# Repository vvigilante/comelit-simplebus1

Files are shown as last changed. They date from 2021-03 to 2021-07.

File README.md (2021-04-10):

# Comelit Simplebus 1 compatible smart audio intercom
If you live in an older building with an audio-only door phone based on the SimpleBus version 1, you may have no choice for upgrading to a smart alternative. This project aims to build an open implementation of a smart doorphone compatible with the comelit simplebus 1 audio protocol, to replace ordinary units such as 2408w/a, 2708W and 2xx8W in general.

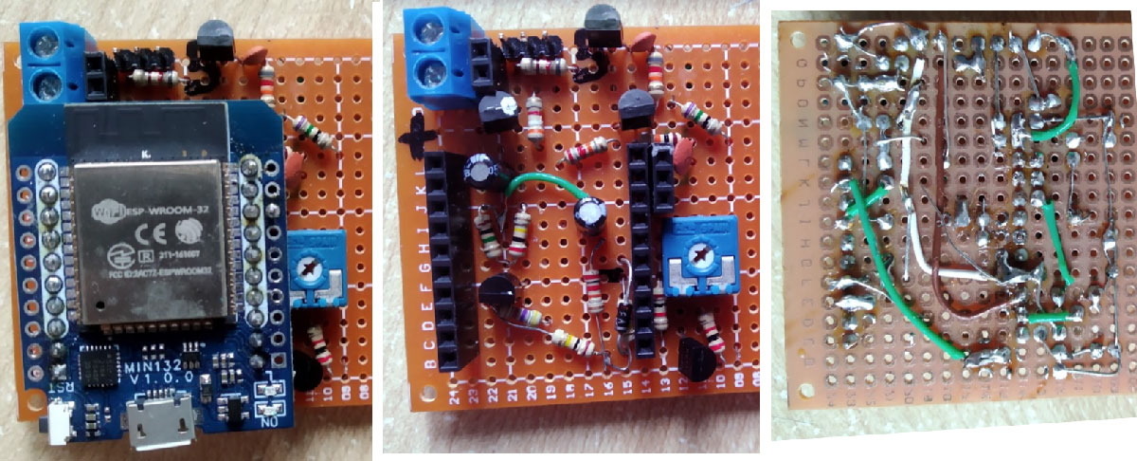
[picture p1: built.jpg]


## Content of the repository
| Dir | Content 
------- | --- 
| libsimplebus | Arduino library that allows to interface with the digital bus 
| web_intercom | Arduino sketch that implements a complete intercom operated by a web interface. 
| sketch_webmonitor | **(temporarily broken)** Arduino sketch that implements a websocket based https interface that logs the messages on the bus, allows to listen to the audio signal and to transmit audio signals from the computer mic. It also allows to initiate calls on the bus, useful for testing. 

## Wiring

Wire according to the wiring diagram; **mind the polarity of the bus!**

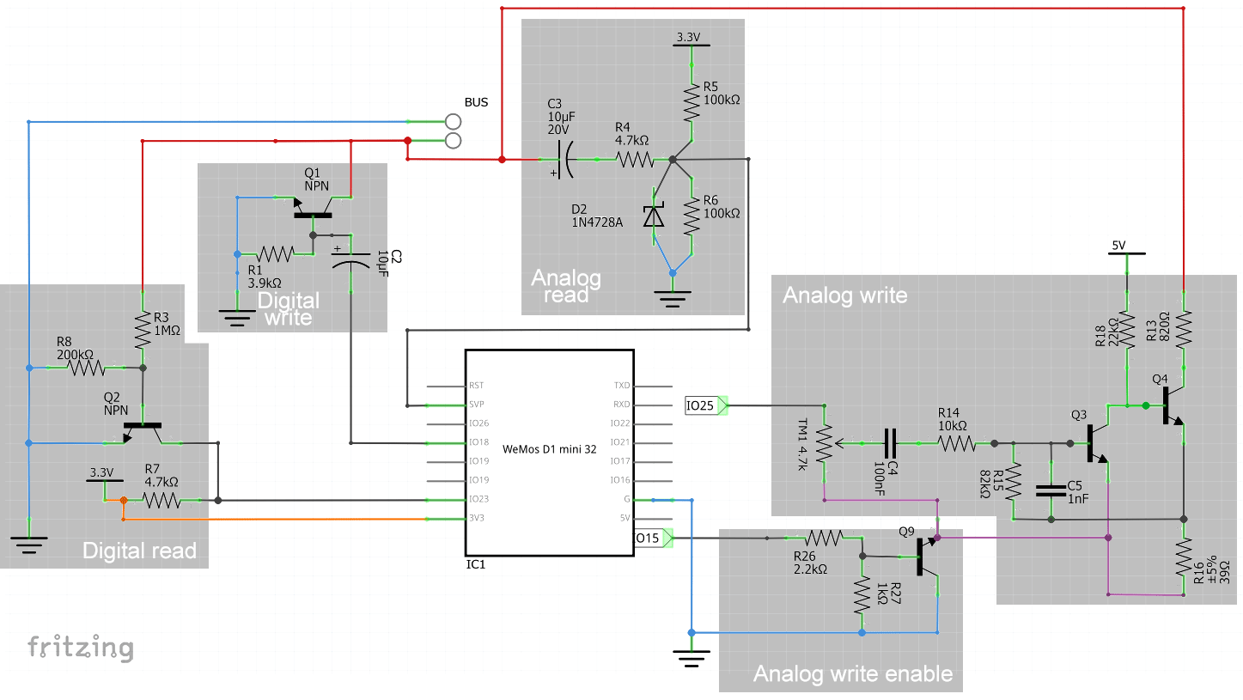
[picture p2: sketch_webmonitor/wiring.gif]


Tested on Wemos D1 mini32 (esp32 arduino core 1.0.5).

### Known issues
* Feedback from the PC speaker back into the mic.

## Protocol

The protocol features a ~24V bus. The units communicate through a digital protocol, by shorting the bus to produce short and long pulses.

Digital messages are composed of a 6 bit command, 8 bit "internal unit id" and 4 bit checksum. The start of a message is signaled by a longer pulse.
The recipient acknowledges every message by sending a sequence of three short pulses.

The audio is sent back and forth as an analog signal in base band on the bus itself once the communication has been established. Its peak-to-peak amplitude is about 2.5 volts.

Example of a communication
```
time: [41.404s] message: [000011 10110000 1010 - CALL 13 chkOK]
time: [41.457s] ack
time: [47.914s] message: [100010 10110000 1010 - PUP1 13 chkOK]
time: [47.961s] ack
time: [48.128s] message: [100011 10110000 0110 - PUP2 13 chkOK]
time: [48.172s] ack
time: [49.524s] message: [000010 10110000 0010 - OPEN 13 chkOK]
time: [49.571s] ack
time: [51.316s] message: [000010 10110000 0010 - OPEN 13 chkOK]
time: [51.362s] ack
time: [53.545s] message: [000010 10110000 0010 - OPEN 13 chkOK]
time: [53.592s] ack
time: [58.221s] message: [010010 10110000 1010 - HUP 13 chkOK]
time: [58.256s] ack
time: [68.616s] message: [111111 11111111 0111 - CLEAR 255 chkOK]
time: [68.952s] message: [111111 11111111 0111 - CLEAR 255 chkOK]
time: [69.289s] message: [111111 11111111 0111 - CLEAR 255 chkOK]
time: [69.626s] message: [111111 11111111 0111 - CLEAR 255 chkOK]
time: [69.963s] message: [111111 11111111 0111 - CLEAR 255 chkOK]
```

## Acknowledgements
Thank you to Antonio Avallone for his help with the electronics of this project

## Previous work
* http://stdio.be/blog/2014-08-17-Fixing-the-intercom-with-logic-analyzer/1
* https://hackaday.com/2019/10/27/reverse-engineering-a-two-wire-intercom/

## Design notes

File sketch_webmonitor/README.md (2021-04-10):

A web interface that:
- shows the bus status (clear / busy in a call, etc)
- logs the messages received on the bus
- allows to start a call to an internal unit
- shows the waveform read from the bus through ADC+DMA
- plays the waveform in real time through the browser

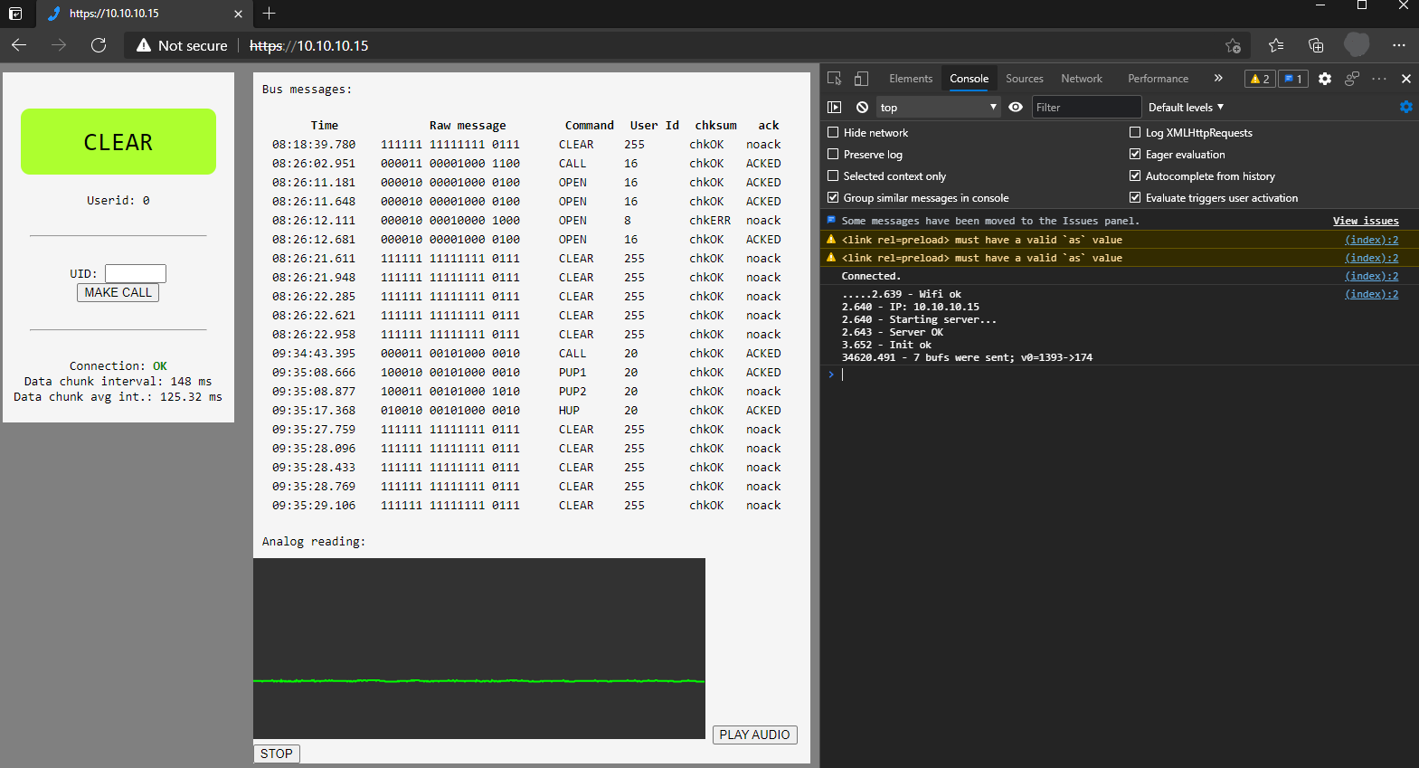
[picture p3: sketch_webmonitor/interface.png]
Interface


## Wiring

Wiring diagram

For reading the bus we use a voltage divider (R2,R3) connected to Q2; Q2 will open during the pulses on the bus, bringing the signal high on IO23 through the R7 pull-up resistor; IO23 is configured to handle rising-edge interrupts.

For writing to the bus we short the two ends of the bus through Q1, which is controlled by the pin IO18 through a capacitor.

For reading the analog voltages through the ADC (on pin GPIO35, SVP) we use the C3 capacitor to remove the 24V direct component, we then bias the signal again using the voltage divider (R5,R6).
The clipper circuit (D2, R4) is meant to limit the voltage spikes caused by the digital communication on the bus. The audio signal has an amplitude of 2.5 v peak to peak.

For writing analog voltages on the bus we use the two stage amplifier made of Q3 and Q4. The signal is generated by the DAC on GPIO25 and fed through a potentiometer and an high-pass filter to the amplifier.
The amplifier is connected to ground through Q9, that can be used to turn the amplifier on and off through a GPIO pin (e.g. 16 in the figure, 15 in the sketch)

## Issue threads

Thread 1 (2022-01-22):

[Dumq Question] Wich power is use external or bus

cynnfx, 2022-01-22:
Hello,

First thank for this work.

I asking myself if this project use bus power or extrnal one.

And if it's use extrenal power if we can use the bus one, like real intercom device (and [this project](https://github.com/plusvic/simplebus2-intercom)

Thanks,

vvigilante, 2022-01-22:
This project uses external power.
It cannot be otherwise because there is not enough power on the bus to power a wifi enabled chip continuously.

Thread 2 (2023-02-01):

Dogital Write

Gurkenflieger, 2023-02-01:
Hello, why are you connecting the digital write output transistor Q1 over a capacitor C2 and resistor R1 , minimizing fluctuations? Why not connecting it directly with a resistor to the IO18.

vvigilante, 2023-02-01:
Let me open by saying that I don't know exactly what's going on.

I think the capacitor there will prevent the micro from holding the gate down for a long time (e.g. in case of software issues and such). You only need to send pulses on the bus, and my understanding is that the capacitor allows you to do that.

Correct me if all this doesn't make sense to you

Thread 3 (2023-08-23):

Identify transistors

vinicentus, 2023-08-23:
Hello!

Would it be possible to document the model numbers of the transistors used in the different parts of the cricuit? As of now they are missing.

I'm trying to build something similar but it's hard to figure out what the different transistors are used for and what specs they need to have.

Br.
Vincent

vvigilante, 2023-08-23:
I used bc327/8 all over.

vinicentus, 2023-08-23:
Thank you! That helps a lot!

vinicentus, 2023-08-23:
Do you want this issue closed or should I leave it open? Btw, [this](https://github.com/vvigilante/comelit-simplebus1/blob/main/sketch_webmonitor/README.md) was very helpful as well for understanding the circuit.

vinicentus, 2023-08-23:
May I still ask what current gain was used? Here are a couple of different versions of the BC327 (more info [here](https://www.el-component.com/bipolar-transistors/bc327) under the Hfe seciton)

vvigilante, 2023-08-23:
BC337-25 maybe? Found that in my purchase history.
I don't have the exact data handy unfortunately. I just grabbed whatever transistors I had laying around at the time. I'm not an EE, but I think it's not going to matter a whole lot. There was not though put into the choice of transistor, basically.

vinicentus, 2023-08-23:
Okay.
Thank you for the answer!
I'll try to build this unit and see how it goes.

vinicentus, 2023-08-26:
Did you by any chance mean BC337? Because they are NPN transistors, as in the schematic. BC327 are PNP transistors, which aren't used at all (it seems).

vvigilante, 2023-08-26:
Yes BC337-25

vinicentus, 2023-08-26:
Yeah, okay, thanks :D

Closed 2023-08-23.

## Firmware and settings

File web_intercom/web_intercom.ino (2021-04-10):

#include "SimplebusIntercom.h"
#include "Logger.h"
#include "WebsocketLogger.h"
#include "audio.hpp"
#include "server.hpp"
#include "SerialLogger.h"
#include <ArduinoOTA.h>

#define RING_INTERVAL_MS 1000

// CONFIGURATION
#define BUS_ID 27
#define BUS_RECEIVE_PIN      GPIO_NUM_5
#define BUS_TRANSMIT_PIN     GPIO_NUM_18
#define LED_BUILTIN          GPIO_NUM_2
#define MIC_ENABLE_PIN       GPIO_NUM_15

#define WIFI_SSID "your-ssid"
#define WIFI_PASS "your-password"


// Global state
unsigned long last_ring_sent=0;
bool audio_enabled = 0;
bool ringer_enabled = 0;
Simplebus* sb = NULL;
SimplebusIntercom* sbi = NULL;
IntercomAudio* sba = NULL;
IntercomServer* svr = NULL;



// Tasks

static void ledTask(void * pvParameters){
  while(1){
      digitalWrite(LED_BUILTIN, LOW);
      int duty = 970;
      if (WiFi.status() != WL_CONNECTED) {
          duty = 500;
      }
      if(audio_enabled){
          duty = 20;
      }
      vTaskDelay(pdMS_TO_TICKS(duty));
      digitalWrite(LED_BUILTIN, HIGH);
      vTaskDelay(pdMS_TO_TICKS(1000-duty));
  }
}
static void audioTask1(void * pvParameters){
  while(1){
      vTaskDelay(pdMS_TO_TICKS(10));
      sba->readbus();
  }
}
static void audioTask2(void * pvParameters){
  while(1){
      vTaskDelay(pdMS_TO_TICKS(10));
      sba->writebus();
  }
}
static void serverTask(void * pvParameters){
  while(1){
        svr->loop();
        ArduinoOTA.handle();
        if(svr->get_num_connected_clients()){
            logger->flush(true);
            sba->send_to_ws();
        }
        logger->flush(true);
        if(ringer_enabled && millis()>=last_ring_sent+RING_INTERVAL_MS){
            svr->server_ws_broadcast("R");
            last_ring_sent = millis();
        }
        vTaskDelay(10);
    }
}

static void busTask(void * pvParameters){
  while(1){
    sbi->loop();
    vTaskDelay(pdMS_TO_TICKS(1));
  }
}




// Logic

void ringerCb(bool enable){
  LOG("Set ringer: %d", enable);
  ringer_enabled=enable;
  if(!enable)
    svr->server_ws_broadcast("r");
}
void audioCb(bool enable){
  LOG("Set audio: %d", enable);
  audio_enabled = enable;
  svr->server_ws_broadcast(enable?"A":"a");
  digitalWrite(MIC_ENABLE_PIN, enable);
}
void audio_to_ws_cb(const uint8_t* data, size_t size){
  if(audio_enabled)
    svr->server_ws_broadcast_bin(data, size);
}
void audio_from_ws_cb(const uint8_t* data, size_t size){
  if(audio_enabled)
    sba->recv_from_ws(data,size);
}
void command_from_ws_cb(char command){
  //LOG("Read %d bytes of audio from ws", size);
  switch(command){
    case 'P':
      sbi->setUserPickup();
      break;
    case 'H':
      sbi->setUserHangup();
      break;
    case 'O':
      sbi->sendOpen();
      break;
    default:
      LOG("Command not understood: %c", command);
      break;
  }
}



void setup(){
  pinMode(LED_BUILTIN, OUTPUT);
  digitalWrite(MIC_ENABLE_PIN, 0);
  pinMode(MIC_ENABLE_PIN, OUTPUT);
  logger = new WebsocketLogger(svr->server_ws_broadcast);
  //logger = new SerialLogger(115200);
  xTaskCreatePinnedToCore ( ledTask, "ledTask", 1024, NULL, 31, NULL, 1 );

  // Digital bus
  sb = new Simplebus(BUS_RECEIVE_PIN, BUS_TRANSMIT_PIN);
  sbi = new SimplebusIntercom(sb, BUS_ID, audioCb, ringerCb);
  
  // Wifi
  WiFi.begin(WIFI_SSID, WIFI_PASS);
  logger->log(false, "Waiting for wifi now");
  while (WiFi.status() != WL_CONNECTED) {
    logger->log(false, ".");
    delay(500);
  }
  LOG("Wifi ok");
  LOG("IP: %s", WiFi.localIP().toString().c_str());
  
  // Server
  svr = new IntercomServer(audio_from_ws_cb, command_from_ws_cb);
  
  // Analog audio
  sba = new IntercomAudio(audio_to_ws_cb);

  // Tasks
  xTaskCreatePinnedToCore ( audioTask1, "audioTask1", 2048, NULL, 30, NULL, 0 );
  xTaskCreatePinnedToCore ( audioTask2, "audioTask2", 2048, NULL, 30, NULL, 0 );
  xTaskCreatePinnedToCore ( busTask, "busTask", 4096, NULL, 29, NULL, 0 );
  xTaskCreatePinnedToCore ( serverTask, "serverTask", 4096, NULL, 30, NULL, 1 );
  
  // OTA
  ArduinoOTA.begin();
  // Make sure there is at least 60k per connection (2 in our case -> 120k)
  LOG("Init ok, free heap: %lu", heap_caps_get_free_size(MALLOC_CAP_8BIT));
}


void loop(){
  vTaskDelay(pdMS_TO_TICKS(500));
}

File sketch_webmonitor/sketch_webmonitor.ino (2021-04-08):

#include "Simplebus.h"
#include "SimplebusState.h"
#include "SimplebusIntercom.h"
#include "CircularQueue.h"
#include "Logger.h"
#include "WebsocketLogger.h"
#include "SerialLogger.h"
void makeCall(int userid);
void setMic(int state);
#include "audio.hpp"
#include "server.hpp"
#include <ArduinoOTA.h>

/* Configuration */
#define QUEUE_SIZE          20
#define ACK_DELAY_TIME_MS   50
#define NOACK_DELAY_TIME_MS 10
/* Wemos pins */
#define BUS_RECEIVE_PIN      GPIO_NUM_5
#define BUS_TRANSMIT_PIN     GPIO_NUM_18
#define LED_BUILTIN          GPIO_NUM_2
#define MIC_ENABLE_PIN       GPIO_NUM_15
/* Wifi settings */
#define WIFI_SSID "your-ssid"
#define WIFI_PASS "your-password"

struct SimplebusMessageStamped{
    unsigned long timestamp = -1;
    SimplebusMessage message;
    bool ack = false;
    String toString(){
      return String(timestamp) + String(" ") + message.toString() + String(ack?" ACKED":" noack");
    }
};

bool mic_enabled = 0;
Simplebus* sb = NULL;
SimplebusIntercom* sbi = NULL;
SimplebusState state;
CircularQueue<SimplebusMessageStamped> queue(QUEUE_SIZE);

TaskHandle_t th0, th1, th2, th3, th4, th5;
int usertocall=0;
static void callTask(void* pvParameters){
  while(1){
    if(usertocall){
        sbi->makeCall(usertocall);
        usertocall = 0;
    }
    vTaskDelay(pdMS_TO_TICKS(100));
  }
}
void makeCall(int userid){
  usertocall = userid;
}
void setMic(int state){
  LOG("Mic enable: %d", state);
  mic_enabled = state;
  digitalWrite(MIC_ENABLE_PIN, state);
}

static void audioreadTask(void * pvParameters){
  while(1){
      vTaskDelay(pdMS_TO_TICKS(10));
      audio_readbus();
  }
}
static void ledTask(void * pvParameters){
  while(1){
      digitalWrite(LED_BUILTIN, LOW);
      int duty = 970;
      if (WiFi.status() != WL_CONNECTED) {
          duty = 500;
      }
      if(mic_enabled){
          duty = 20;
      }
      vTaskDelay(pdMS_TO_TICKS(duty));
      digitalWrite(LED_BUILTIN, HIGH);
      vTaskDelay(pdMS_TO_TICKS(1000-duty));
  }
}
static void audiowriteTask(void * pvParameters){
  while(1){
      vTaskDelay(pdMS_TO_TICKS(10));
      audio_writebus();
  }
}

static void serverTask(void * pvParameters){
  while(1){
        server_loop();
        ArduinoOTA.handle();
        if(get_num_connected_clients()){
          while(!queue.isEmpty()){
            SimplebusMessageStamped* element = queue.pop();
            sendmessage(element);
          }
          audio_send_to_ws();
        }
        logger->flush(true);
        vTaskDelay(10);
    }
}

static void busTask(void * pvParameters){
  while(1){
    SimplebusMessageStamped m;
    m.message = sb->getMessage(&m.timestamp);
    if(m.message.valid){
      vTaskDelay(pdMS_TO_TICKS(ACK_DELAY_TIME_MS));
    }else{
      vTaskDelay(pdMS_TO_TICKS(NOACK_DELAY_TIME_MS));
    }
    unsigned long ack_time = sb->getAck();
    if(m.message.valid){
        // A new message has arrived
        if(ack_time>=m.timestamp){
            m.ack = true;
        }
        state.feed_message(m.message);
        if(m.ack){
            state.feed_ack();
        }
        queue.push(&m);
    }
  }
}

void setup(){
  pinMode(LED_BUILTIN, OUTPUT);
  digitalWrite(MIC_ENABLE_PIN, 0);
  pinMode(MIC_ENABLE_PIN, OUTPUT);
  logger = new WebsocketLogger();
  //logger = new SerialLogger(115200);
  
  xTaskCreatePinnedToCore ( ledTask, "ledTask", 1024, NULL, 31, &th5, 1 );
  
  sb = new Simplebus(BUS_RECEIVE_PIN, BUS_TRANSMIT_PIN);
  sbi = new SimplebusIntercom(sb, 0);
  WiFi.begin(WIFI_SSID, WIFI_PASS);
  logger->log(false, "Waiting for wifi now");
  while (WiFi.status() != WL_CONNECTED) {
    logger->log(false, ".");
    delay(500);
  }
  LOG("Wifi ok");
  LOG("IP: %s", WiFi.localIP().toString().c_str());
  server_setup();
  audio_setup();
  xTaskCreatePinnedToCore ( busTask, "busTask", 1024, NULL, 29, &th0, 0 );
  xTaskCreatePinnedToCore ( callTask, "callTask", 1024, NULL, 30, &th1, 0 );
  xTaskCreatePinnedToCore ( audioreadTask, "audioreadTask", 2048, NULL, 30, &th2, 0 );
  xTaskCreatePinnedToCore ( audiowriteTask, "audiowriteTask", 2048, NULL, 30, &th3, 0 );
  xTaskCreatePinnedToCore ( serverTask, "serverTask", 4096, NULL, 30, &th4, 1 );
  ArduinoOTA.begin();
  // Make sure there is at least 60k per connection (2 in our case -> 120k)
  LOG("Init ok, free heap: %lu", heap_caps_get_free_size(MALLOC_CAP_8BIT));
}

void sendmessage(SimplebusMessageStamped* element){
  String state_str = String(state.get_state());
  String userid_str = String(state.get_userid());
  String message = state_str+String(',')+userid_str+String(',')+element->toString();
  server_ws_broadcast(message.c_str());
}

void loop(){
  vTaskDelay(pdMS_TO_TICKS(500));
}

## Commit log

2020-11-29 wiring diagram
2020-11-30 attribute needed for latest version of arduino-esp core
2020-11-30 fix wrong message + adjust min start time
    [SimplebusMessage.h]
2020-12-04 disable interrupt before sleep.
2021-01-14 Fix python server crash when socket closed by client
2021-03-16 Bus interface ported to ESP32
2021-03-19 arduino lib
2021-03-20 fixed frequency problem + wiring diagram
2021-03-22 fix adc losing part of the data.
    [sketch_webmonitor.ino]
2021-03-22 hide debug prints
2021-03-22 fix read errors (new wiring)
2021-04-10 web intercom implementation
    [wiring.fzz]
2021-07-01 fix wiring
